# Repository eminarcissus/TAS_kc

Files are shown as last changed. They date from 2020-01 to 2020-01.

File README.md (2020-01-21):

### Two-Axis Sculpt Keycaps

#### Renders:
TAS_profile_3x6_render
TAS_profile_3x6_render2
TAS_profile_5x6_render1
TAS_profile_ergo_render

#### Production:
* The recommended method for 3D printing these keycaps is stereolithography (SLA), selective laser sintering is also a valid method but results in more grainy texture and less consistent dimensions. Filament deposition printing (FDM) can also be used but keycap stem fitment may be compromised, more discussion on this in the design notes section

* Currently supported printing methods:
    * Selective Laser Sintering (SLS): **Supported**
        * Individual keycap models in `./keycaps/sls/stl`
        * Layouts in `./layouts/sls/stl`

    * Stereolithography (SLA): **Supported**
        * Individual keycap models in `./keycaps/sla/stl`

    * Filament Deposition Printing (FDM): **Not yet supported**

* **SLA**: The keycaps can be printed individually, or by arranging selected keycap models in slicing software, such as [Prusa Slicer](https://www.prusa3d.com/prusaslicer/)
    * The layout of keycaps for SLA will vary depending on the printer being used, as consumer-tier printers are limited in the quantity of keycaps being printed at once due to build plate area as well as model cross-sectional area being printed at one time
        * I recommend downloading individual keycap models and arranging them to suit the SLA printer being used
    * Example SLA-layout created using Prusa Slicer for printing with an Anycubic Photon:
    prusa_slicer_layout

* **SLS**: The keycaps can be sent to a 3D printing service such as [3D Hub](https://www.3dhubs.com/) and made with SLS Nylon

----

#### Supported layouts:
##### Planck:
planck_layout_render
* SLS: Can be made by printing the `./layouts/stl/TAS_profile_layout_4x6_a.stl` and `./layouts/stl/TAS_profile_layout_4x6_b.stl` layout files

##### Preonic:
preonic_layout_render
* SLS: Can be made by printing the `./layouts/stl/TAS_profile_layout_5x6_a.stl` and `./layouts/stl/TAS_profile_layout_5x6_b.stl` layout files

##### Corne
corne_layout_render
* SLS: Can be produced by printing out two copies of the `./layouts/stl/TAS_profile_layout_4x6_c.stl` file

----

#### Design notes:

* The keycaps are directly modelled in Solidworks, parametric modelling would be a more precise approach

* The base set of TAS-profile keycaps consists of 3 rows and 4 columns
    * The C0 column has only 1 axis of sculpt (x axis), like a typical set of sculpted SA-profile keycaps
    * Columns C1-C3 are sculpted in two axes (x and y axes), scooping up towards the outer/C3 column, and down towards the home/R1 row

3x4_base_set

* 3x5, 3x6, 4x5, 4x6... etc. layouts can be made by mirroring the caps with the "C0" column as the mirror axis
    * A 5 row layout is possible by using the `./keycaps/stl/rn` number row models

3x6_set

* The bottom row (R3) leaves room for customization, depending on the keyboard they will be used on
* The bottom row I decided to use consists of keycaps from the home/R1 row, as is typical with SA-profile keycaps along with a 1.25 unit thumb key as seen on keyboards like the [Corne](https://github.com/foostan/crkbd)

4x6_set

* The models' stem slots are sized differently for SLA and SLS printing:
    * SLS models have narrower stem slots: 1.17 mm, which should result in a snug fit
    * SLA models have more detailed stem slots and are larger: 1.325/1.425mm
        * Tested on Kailh Box and Pro Heavy stems

sls_stem_dimensions
sla_stem_dimensions

* The geometry of the keycap is defined using the following parameters:
    1) Base square side length
    2) Top plane center height
    3) Top square side length
    4) Vertex length (2+ vertices need to be defined)
    5) Sculpt depth
    6) Vertex tapered fillet radii

parameters_legend

tapered_fillet_radii_legend

* Some parameters are held constant for the keycaps, these are the parameter values I used for my set:
    * Base square side length = 18.50mm
    * Top square side length = 12.50mm
        * **Note**: This is true for 1 unit (square) keycaps, 1.25+ unit sized keycaps have a rectangular top/bottom "square" and these parameters need to be multiplied by a factor depending on the size
            * e.g.: 1.25 unit keycaps have dimensions  18.50mm x 1.25(18.50mm) for the base rectangle side length and 12.50mm x 1.25(12.50mm) for the top rectangle side length
    * Sculpt depth = 0.80mm
        * This is set to 1.0mm for the keycaps in the place of "F" and "J" on a QWERTY layout
    * Vertex tapered fillet radius 1 = 2.00mm
    * Vertex tapered fillet radius 2 = 0.50mm

----

### To-do:

----
###### Models were created in Solidworks, then exported as STL. Feel free to use/modify/redistribute.

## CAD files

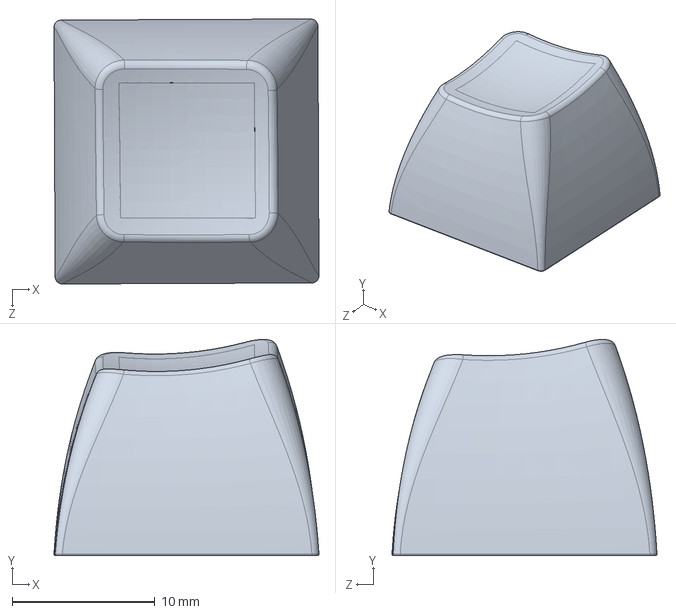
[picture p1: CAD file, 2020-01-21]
keycaps/SLA/sldprt/r0/r0_c3.SLDPRT
18.6 x 15.1 x 18.6 mm

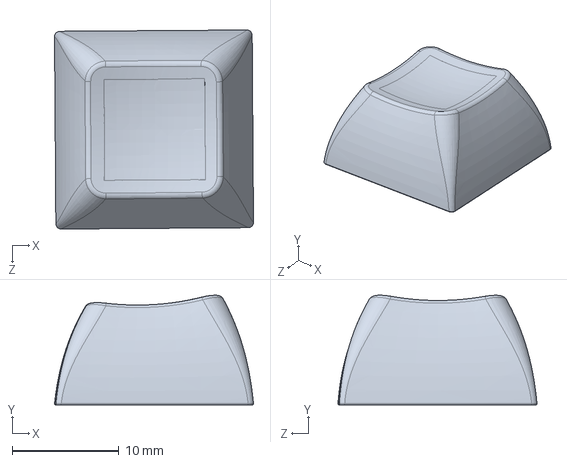
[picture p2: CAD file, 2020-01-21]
keycaps/SLA/sldprt/r1/r1_c1.SLDPRT
18.6 x 10.3 x 18.6 mm

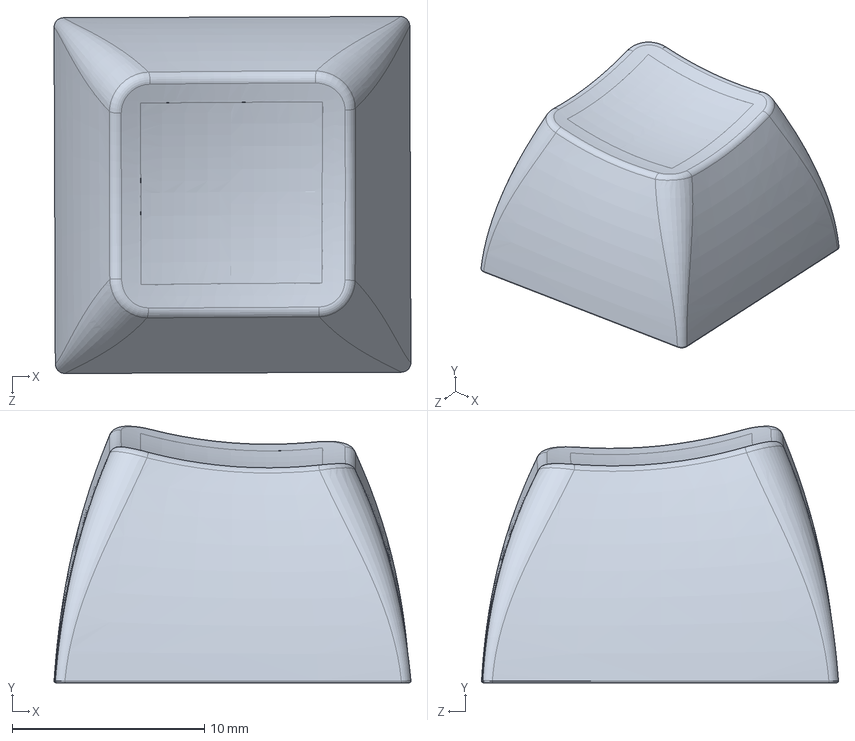
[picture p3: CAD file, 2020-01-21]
keycaps/SLA/sldprt/r2/r2_c2.SLDPRT
18.5 x 13.3 x 18.5 mm

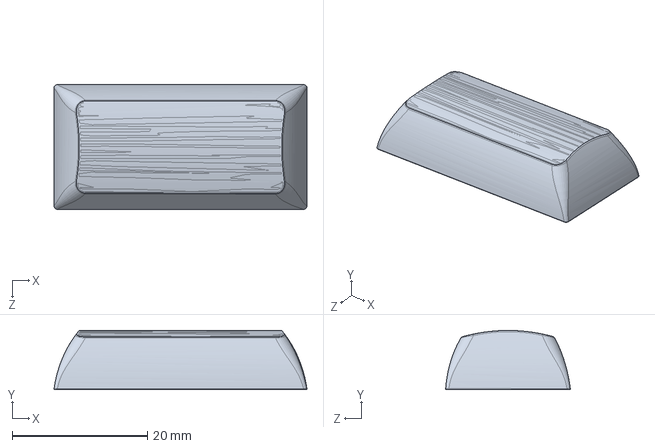
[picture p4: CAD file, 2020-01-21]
keycaps/SLA/sldprt/r3/r3_2u.SLDPRT
37.5 x 8.75 x 18.5 mm

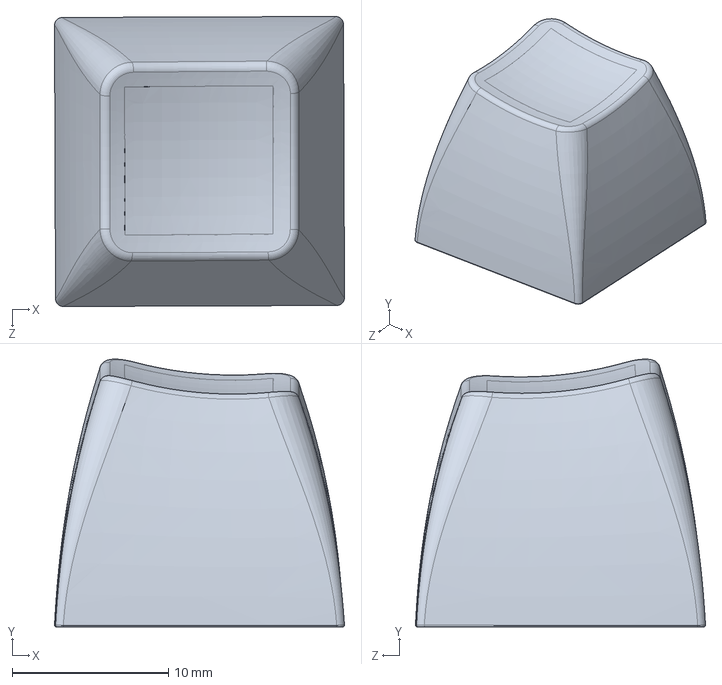
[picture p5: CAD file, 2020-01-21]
keycaps/SLA/sldprt/rn/rn_c3_mirrored.SLDPRT
18.6 x 17.1 x 18.6 mm

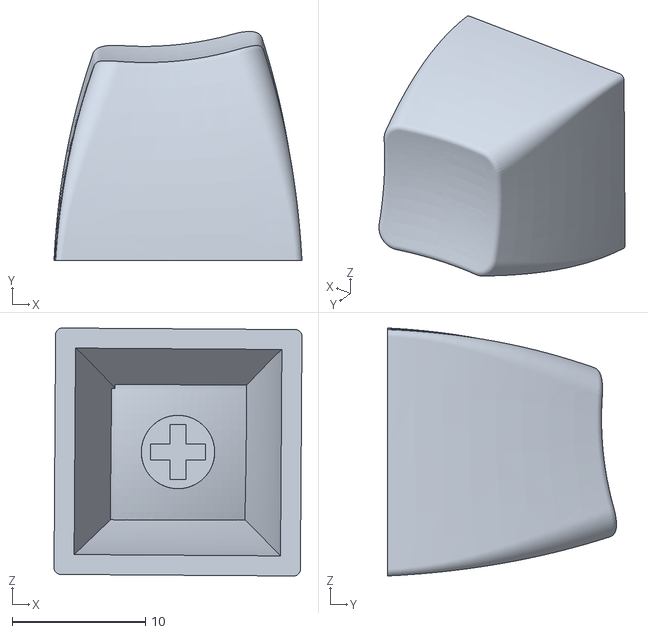
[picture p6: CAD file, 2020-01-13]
keycaps/SLA/stl/r0/r0_c4.STL
18.6 x 17.2 x 18.6

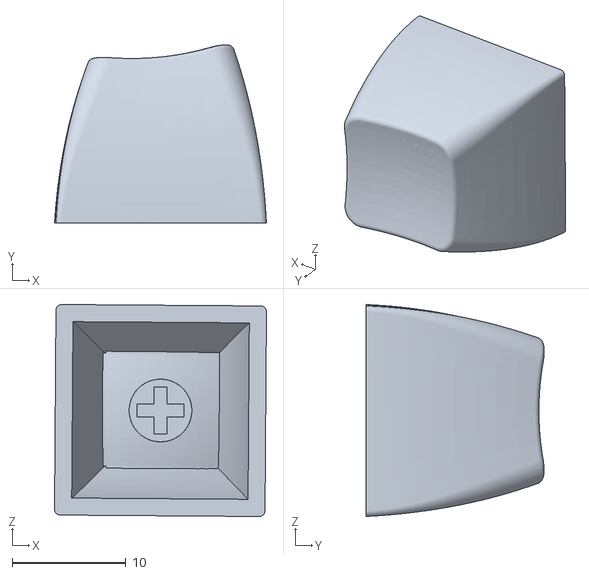
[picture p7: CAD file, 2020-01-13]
keycaps/SLA/stl/r1/r1_c4.STL
18.6 x 15.7 x 18.6

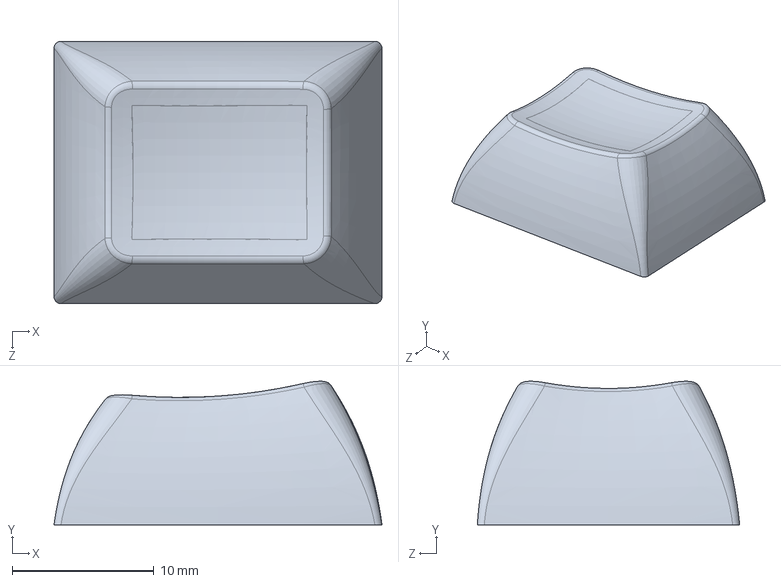
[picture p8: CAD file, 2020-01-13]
keycaps/SLS/sldprt/r3/r3-1.25u.SLDPRT
23.1 x 10.1 x 18.5 mm

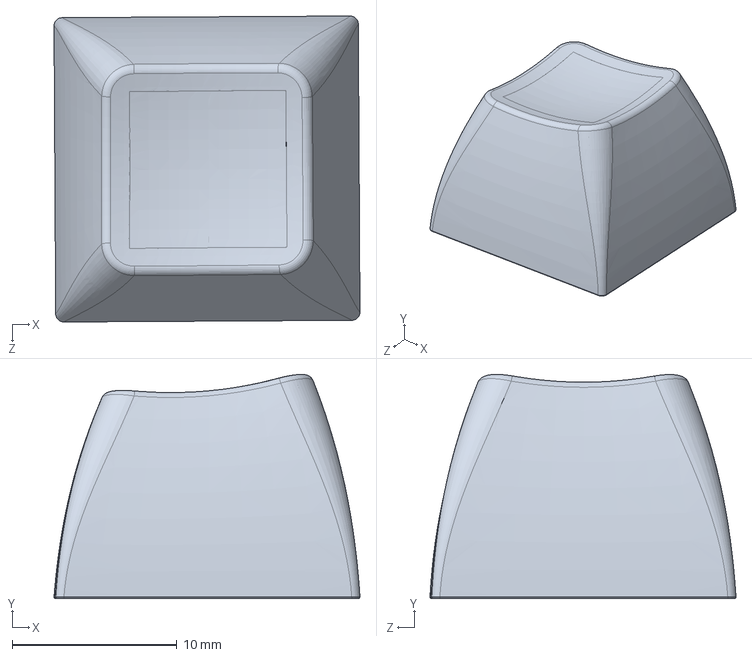
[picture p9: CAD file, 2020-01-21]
keycaps/SLA/sldprt/r1/r1_c3.SLDPRT
18.6 x 13.6 x 18.6 mm

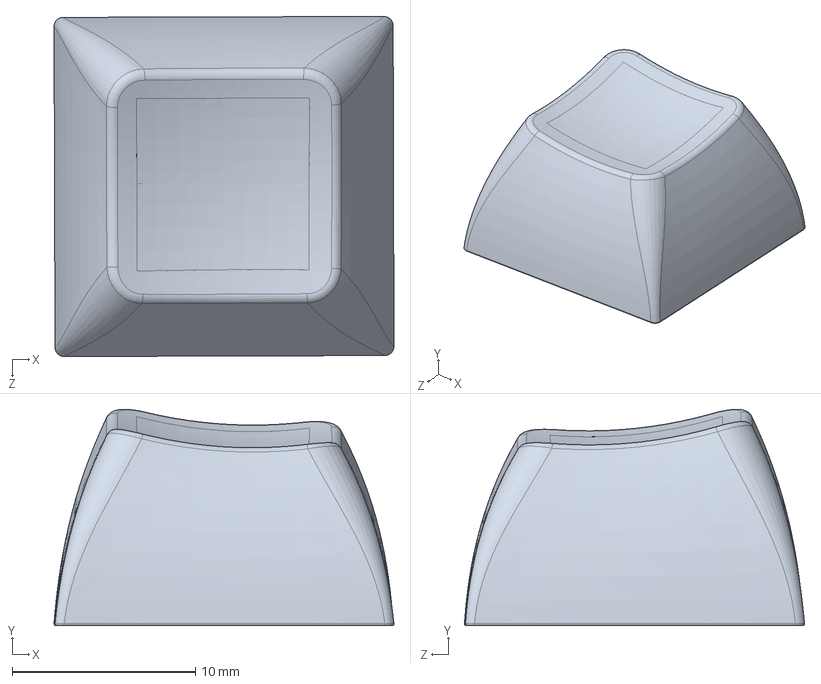
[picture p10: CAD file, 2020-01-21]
keycaps/SLA/sldprt/r2/r2_c1.SLDPRT
18.5 x 11.8 x 18.5 mm

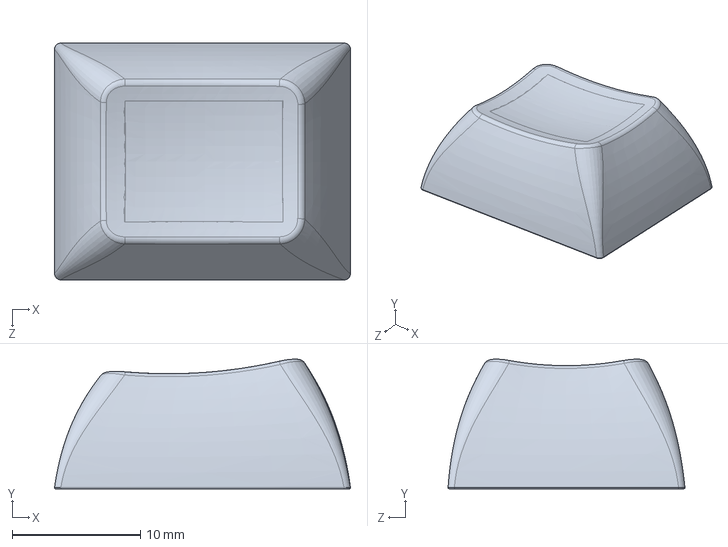
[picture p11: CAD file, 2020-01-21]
keycaps/SLA/sldprt/r3/r3-1.25u.SLDPRT
23.1 x 10.1 x 18.5 mm

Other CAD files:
keycaps/SLA/stl/r2/r2_c4.STL
keycaps/SLA/stl/rn/rn_c4.STL
keycaps/SLS/sldprt/r0/r0_c4.SLDPRT
keycaps/SLS/sldprt/r2/r2_c4.SLDPRT
keycaps/SLA/sldprt/r0/r0_c2.SLDPRT
keycaps/SLA/sldprt/rn/rn_c2_mirrored.SLDPRT
keycaps/SLS/sldprt/r1/r1_c4.SLDPRT
keycaps/SLA/sldprt/r0/r0_c0.SLDPRT
keycaps/SLA/sldprt/r0/r0_c1.SLDPRT
keycaps/SLA/sldprt/r1/r1_c0.SLDPRT
keycaps/SLA/sldprt/r1/r1_c2.SLDPRT
keycaps/SLA/sldprt/r2/r2_c0.SLDPRT
keycaps/SLA/sldprt/r2/r2_c3.SLDPRT
keycaps/SLA/sldprt/rn/rn_c0.SLDPRT
keycaps/SLA/sldprt/rn/rn_c1.SLDPRT
keycaps/SLA/sldprt/rn/rn_c1_mirrored.SLDPRT
keycaps/SLA/sldprt/rn/rn_c2.SLDPRT
keycaps/SLA/sldprt/rn/rn_c3.SLDPRT
keycaps/SLA/stl/r0/r0_c0.STL
keycaps/SLA/stl/r0/r0_c1.STL
keycaps/SLA/stl/r0/r0_c2.STL
keycaps/SLA/stl/r0/r0_c3.STL
keycaps/SLA/stl/r1/r1_c0.STL
keycaps/SLA/stl/r1/r1_c1.STL
keycaps/SLA/stl/r1/r1_c2.STL
keycaps/SLA/stl/r1/r1_c3.STL
keycaps/SLA/stl/r2/r2_c0.STL
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

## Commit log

2020-01-13 updated keycap models to 1.5mm thick
    [r0_c0.SLDPRT, r0_c0.STL, r0_c1.SLDPRT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]
2020-01-21 added updated models for SLA printing
    [r0_c0.SLDPRT, r0_c0.STL, r0_c1.SLDPRT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]
2020-01-25 added photon stl layouts
